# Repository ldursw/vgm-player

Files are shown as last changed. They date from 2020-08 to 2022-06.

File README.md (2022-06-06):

# VGM Player

This project allows VGM (Video Game Music) files from Sega Master System, Sega Game Gear,
and Sega Mega Drive/Genesis to be played on real hardware using the YM2612 sound chip and
the Teensy 3.6 board.

## Features

- Support for Master System, Game Gear, Mega Drive/Genesis
- Standalone player using the SD Card slot
- Can be controlled by a computer using the USB port
- Correct volume for PSG and FM
- Integration with emulators available
- Supports emulated and discrete SN76489
- Uses the Mega Amp circuit for amplification
- Hardware support for Teensy 3.6 and Arduino Due
- Player support for Windows and Linux (experimental)

## Supported boards

| Board | SD Card | Stream | Real PSG | Emulated PSG |
| --- | --- | --- | --- | --- |
| Teensy 3.6 | ✔️ | ✔️ | ✔️ | ✔️ |
| Arduino Due | ❔ | ✔️ | ✔️ | ✔️ |

✔️ Fully supported  
❔ Not tested  

## Demo
- [Instruction streaming from PC](https://www.youtube.com/watch?v=saAEF2lk2_Y)
- [Emulator with hardware sound](https://www.youtube.com/watch?v=Mupbj-XCC5c)
- [44.1kHz playback](https://www.youtube.com/watch?v=DkkqFxyVbDQ)
- [Music recordings](https://www.youtube.com/watch?v=EpjxUjE8uks)

## Difference between other implementations

### PSG

One of the biggest differences between this project and other implementations is that
an emulated PSG is used instead of the discrete SN76489. It is
[widely known](https://www.smspower.org/Development/SN76489#TheLinearFeedbackShiftRegister)
that the Sega version has some differences mainly in the noise channel.

For example, most games get a [weird artifact](https://gitcdn.link/cdn/ldursw/vgm-player/main/assets/panicpuppet-discrete.ogg) instead
of the [expected noise channel](https://gitcdn.link/cdn/ldursw/vgm-player/main/assets/panicpuppet-emulated.ogg).
After Burner II has a constant tone on a [discrete chip](https://gitcdn.link/cdn/ldursw/vgm-player/main/assets/afterburner-discrete.ogg)
whereas [on emulation](https://gitcdn.link/cdn/ldursw/vgm-player/main/assets/afterburner-emulated.ogg) it sounds right.

When using an emulated PSG the microcontroller will emulate the chip and the output is
sent to the `DAC0` pin at 44.1 kHz.

If you want to use a discrete PSG anyway, all you have to do is uncomment `-DUSE_REAL_PSG`
on `hardware/platformio.ini`, connect the `D0..D7` lines from the shift register to the
SN76489 and connect `/WE` to pin 29 though a voltage converter.

### Remote control

Another difference is that the hardware can be controlled via a companion application
written in .NET Core that accepts a generic input class and sends to the hardware via
USB and also displays the current state on screen.

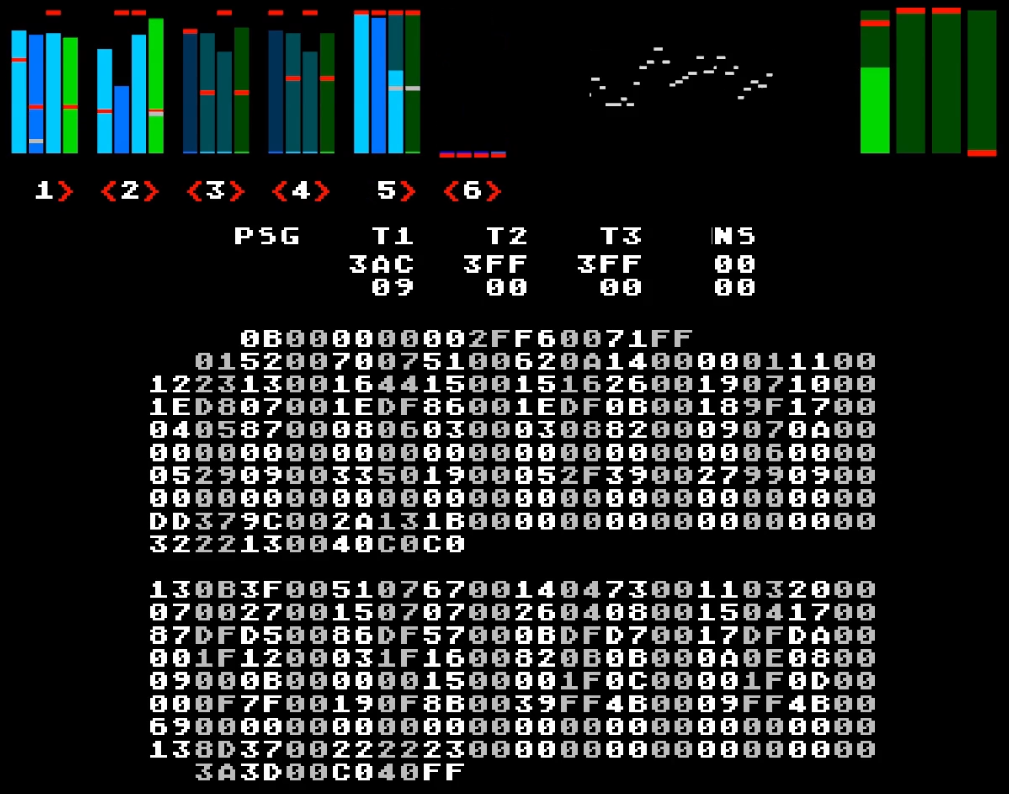
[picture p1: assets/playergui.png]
GUI


There are 3 available input methods. `VgmFile` reads standard `.vgm` and `.vgz` files.
`VgmPipe` creates a named pipe `vgmstream` that accepts commands from other applications,
such as emulators. `VgmPCM` streams 44.1 kHz signed 8-bit mono PCM files to the chip.

## Compiling and Running the project

To compile the code for the hardware you will need [PlatformIO](https://platformio.org/).
You can use the CLI or an IDE with extension support such as Visual Studio Code. After
installing PlatformIO just open the `hardware` directory and upload the code to the board.

To compile the player application you will need the
[.NET Core SDK](https://dotnet.microsoft.com/download). You can use the CLI or an IDE
such as Visual Studio Community or Visual Studio Code. On Linux you may have to install
the `libSDL2` package.

## License

All files in this repository are licensed under GNU General Public License Version 3.

## Credits

Thank you very much for all these awesome people

- Maxim - PSG emulation code
- Dave, Maxim, Valley Bell - VGM Format
- zamaz - [DGen/SDL emulator](https://sourceforge.net/projects/dgen/files/dgen/1.33/)
- Softdev, Eke-Eke - [Genesis Plus GX emulator](https://github.com/ekeeke/Genesis-Plus-GX)
- Ace, Villahed94 - [Mega Amp](https://www.sega-16.com/forum/showthread.php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)
- Stephane-D - [XGM Tool and XGM Player](https://github.com/Stephane-D/SGDK/tree/master/sample/xgm-player)
- SDL Community - [SDL](https://www.libsdl.org/)
- greiman - [SdFat library](https://github.com/greiman/SdFat)
- ivanseidel - [DueTimer library](https://github.com/ivanseidel/DueTimer)

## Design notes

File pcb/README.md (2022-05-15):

## VGM Player PCB

Schematic, KiCad 6 project and gerber files for the VGM player using Teensy 3.6.

This is a 2-layer board made with tolerances compatible with JLCPCB.

## Bill of materials

| Quantity | Item | Notes |
|---|---|---|
| 55 | Femake header socket | 48 for teensy, 7 for SI5351 |
| 10 | Breakaway male headers | 4 for the SX1308 module |
| 4 | 100k SMD 0805 resistor | |
| 3 | 10uF SMD 0805 ceramic capacitor | |
| 3 | 0.1uF SMD 0805 ceramic capacitor | |
| 2 | 47pF THT 2.54' pitch ceramic capacitor | Can be replaced with SMD 0805 |
| 2 | 1uF, 16V electrolytic capacitor | |
| 2 | 10uF, 25V electrolytic capacitor | |
| 2 | 2.2k SMD 0805 resistor | |
| 2 | 4.7k SMD 0805 resistor | |
| 2 | Jumper cap | |
| 1 | 2.1mm Barrel Jack | |
| 1 | SX1308 Step-Up Converter | |
| 1 | 7805 Regulator, TO-220 | |
| 1 | 100uH Inductor CD105 | |
| 1 | Teensy 3.6 with pins | |
| 1 | TXS0108E, TSSOP-20 | |
| 1 | 24-pin DIP socket, wide | |
| 1 | 3.5mm headphone jack, female | |
| 1 | AMS1117-3.3 regulator | |
| 1 | 330r SMD 0805 resistor | |
| 1 | 470r SMD 0805 resistor | |
| 1 | 680r SMD 0805 resistor | |
| 1 | TL072 op-amp | |
| 1 | Adafruit SI5351 Clock Generator | |
| 1 | 74HC595 shift register, SOP-16 | |

## Assembly instructions

- Solder all components but leave the YM2612, Teensy, and clock generator disconnected.
- Make sure the jumper JP2 (near the 7805) is removed.
- Set the jumper J3 (near the barrel jack) to `* [* *] *` (EXT to center pin).
- Apply 5V to the barrel jack, center positive.
- Adjust the step-up module until it reaches 8V at the output.
- Remove power.
- Add a jumper to JP2 and move J3 to `[* *] * *` (VIN to center pin).
- Plug the Teensy, YM2612, and the clock generator into the board.
- Plug the headphone jack to line-in or a powered speaker.
- Connect the Teensy to the PC with an USB cable.
- Use the player in this repo to play music from file or emulator.

## 3D Render





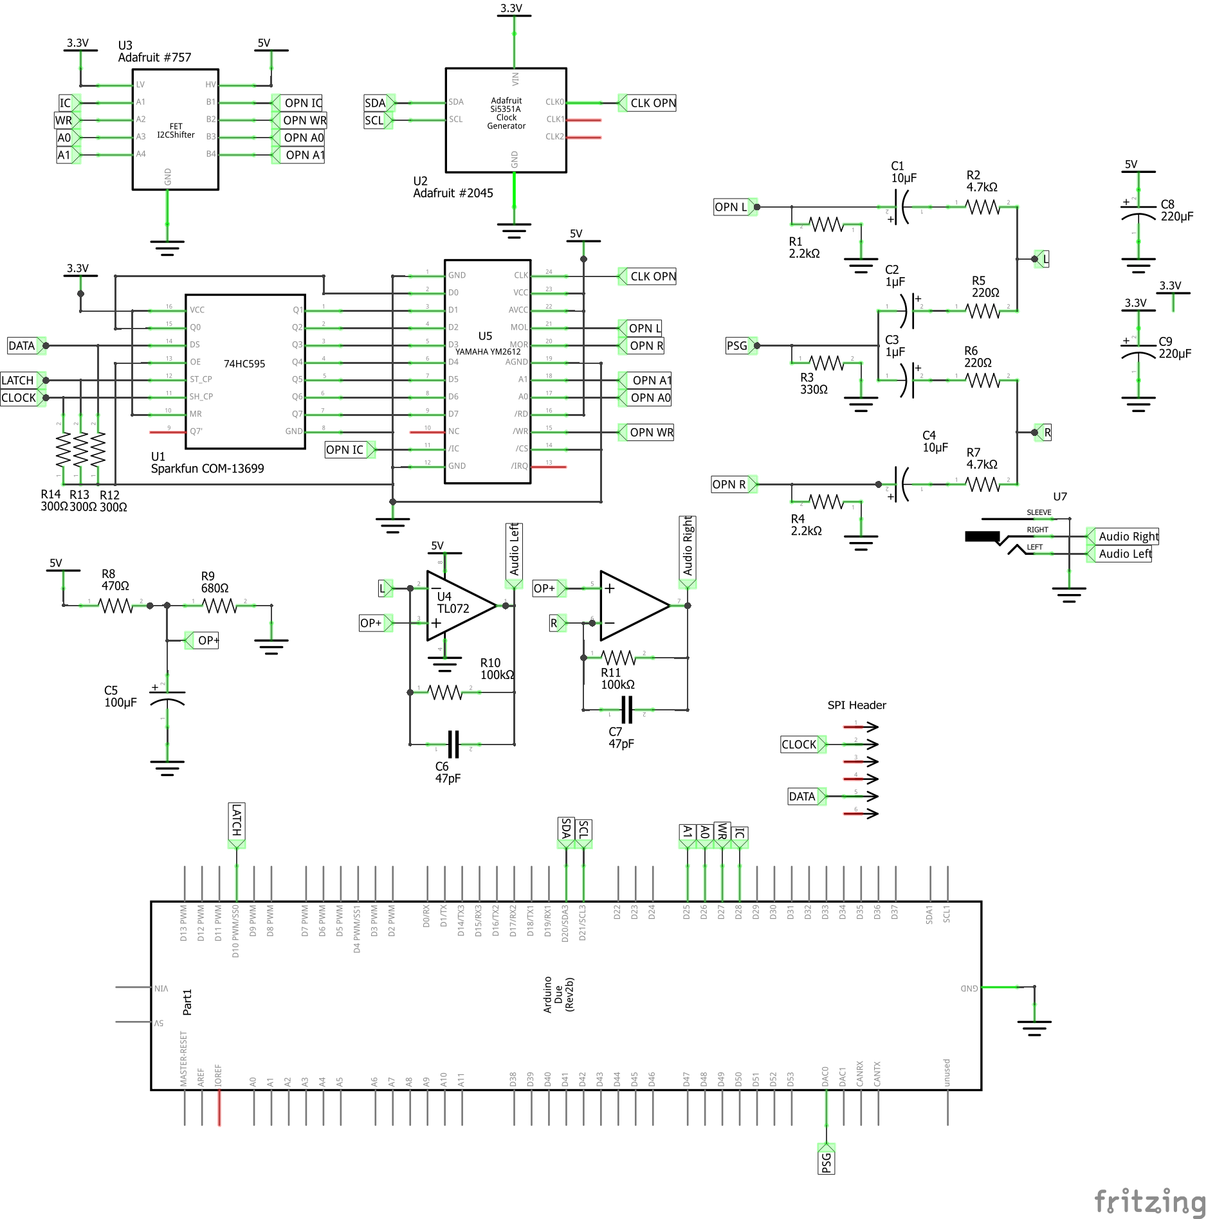
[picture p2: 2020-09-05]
schematics/hardware-due_schem.png

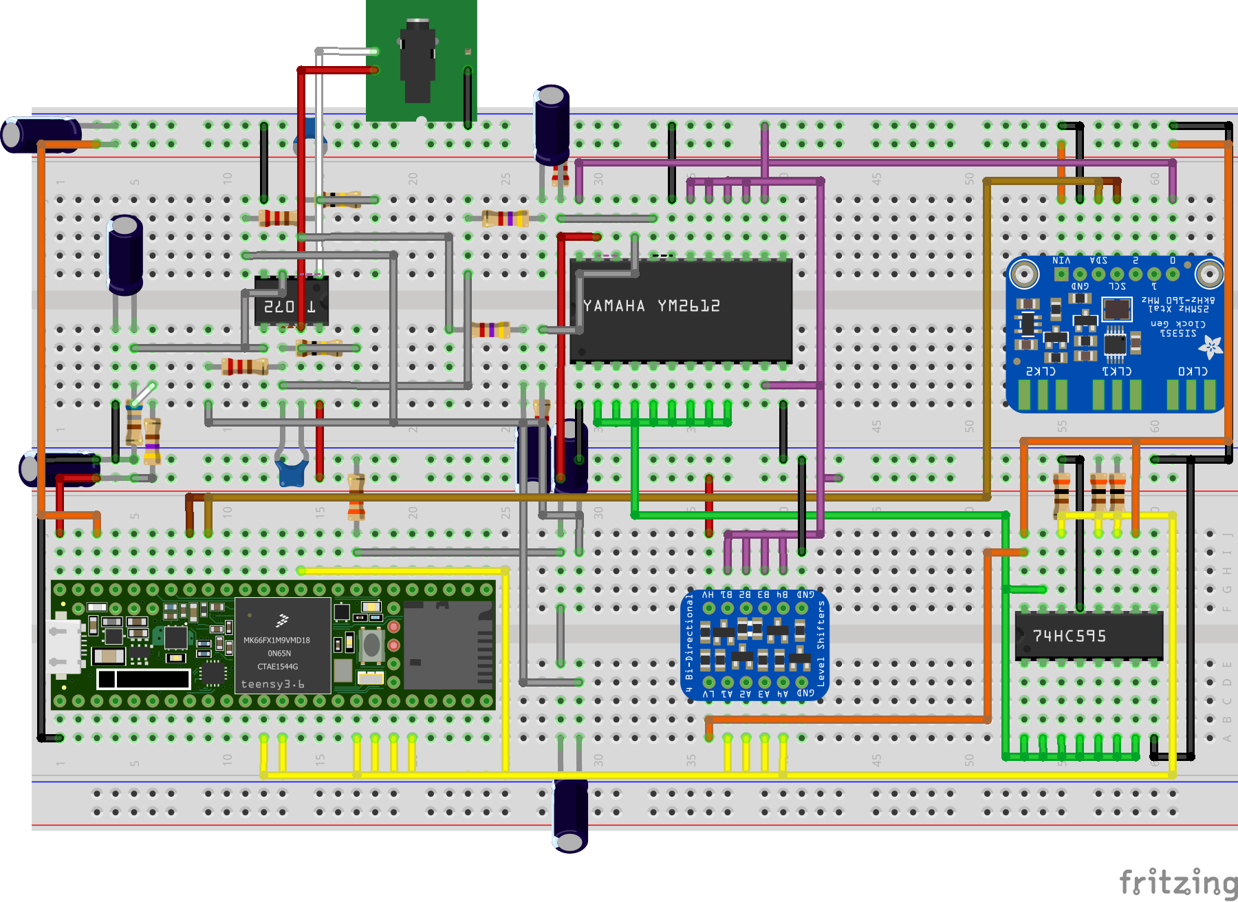
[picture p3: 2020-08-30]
schematics/hardware-teensy36_bb.png

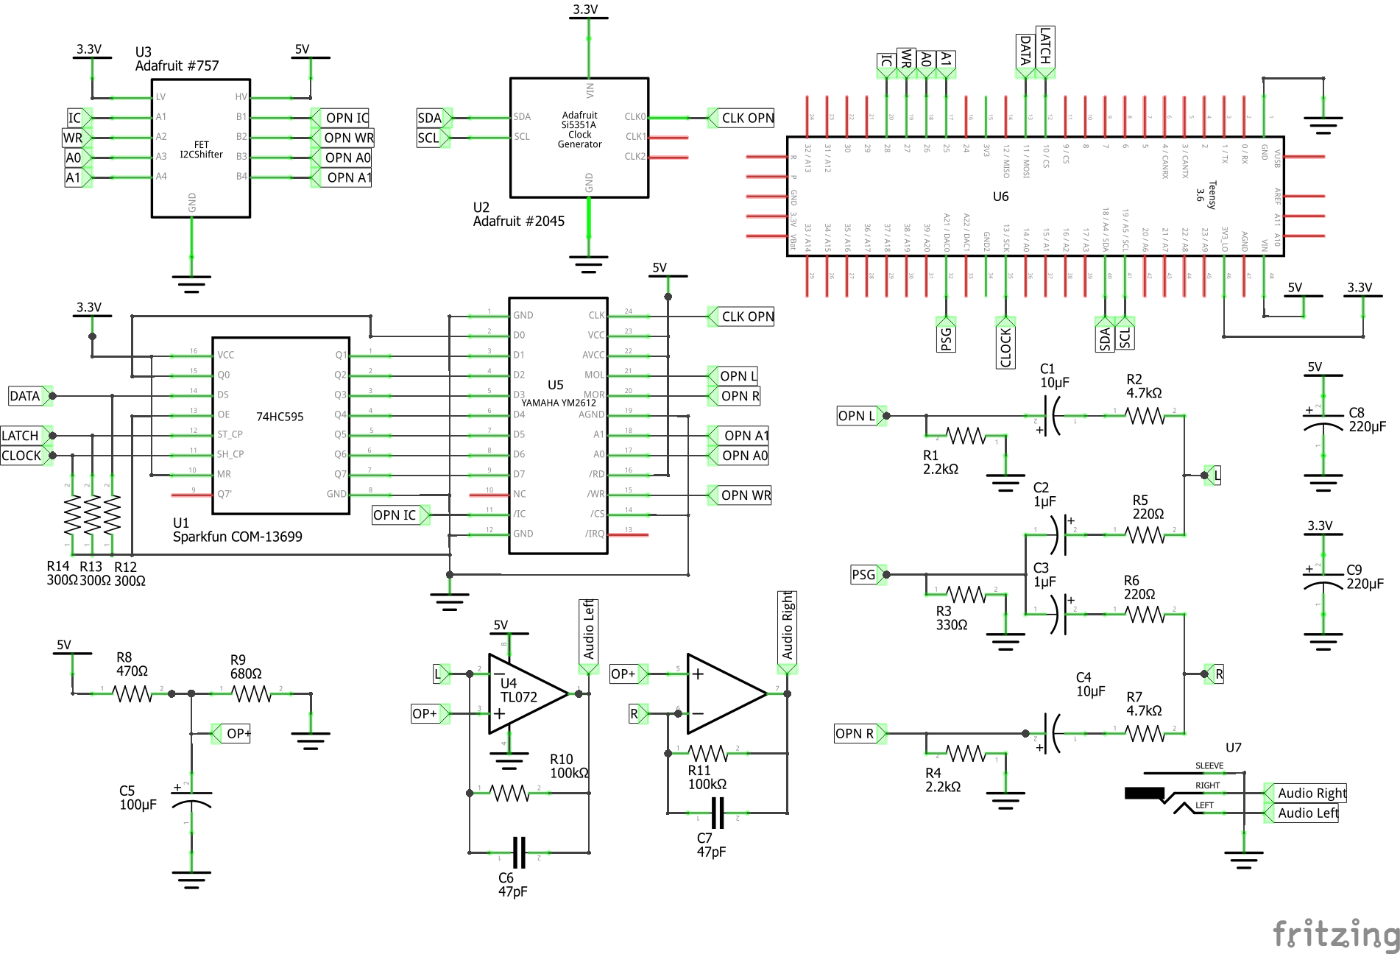
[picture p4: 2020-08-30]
schematics/hardware-teensy36_schem.png

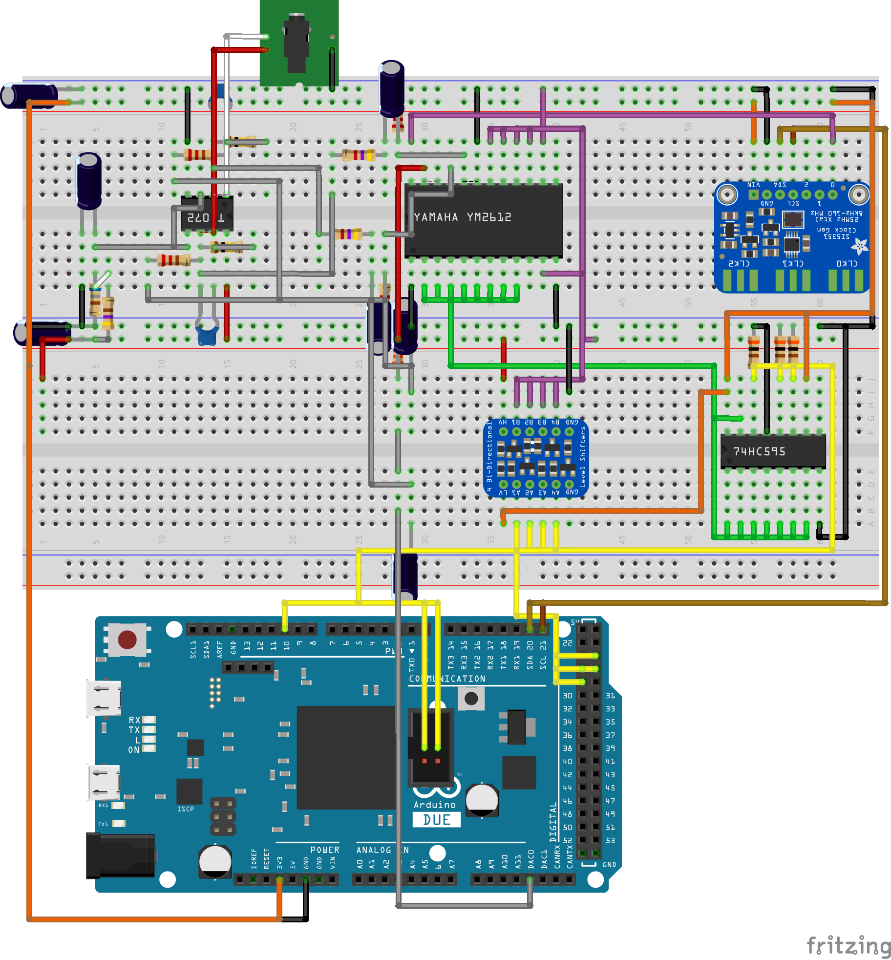
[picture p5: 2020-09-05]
schematics/hardware-due_bb.png

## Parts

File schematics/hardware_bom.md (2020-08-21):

### Assembly List

| Label | Part Type | Properties |
| --- | --- | --- |
C1 | Electrolytic Capacitor | voltage 6.3V; capacitance 10µF; package 100 mil [THT, electrolytic]
C2 | Electrolytic Capacitor | voltage 6.3V; capacitance 1µF; package 100 mil [THT, electrolytic]
C3 | Electrolytic Capacitor | voltage 6.3V; capacitance 1µF; package 100 mil [THT, electrolytic]
C4 | Electrolytic Capacitor | voltage 6.3V; capacitance 10µF; package 100 mil [THT, electrolytic]
C5 | Electrolytic Capacitor | voltage 6.3V; capacitance 100µF; package 100 mil [THT, electrolytic]
C6 | Ceramic Capacitor | voltage 6.3V; capacitance 47pF; package 100 mil [THT, multilayer]
C7 | Ceramic Capacitor | voltage 6.3V; capacitance 47pF; package 100 mil [THT, multilayer]
C8 | Electrolytic Capacitor | voltage 6.3V; capacitance 220µF; package 100 mil [THT, electrolytic]
C9 | Electrolytic Capacitor | voltage 6.3V; capacitance 220µF; package 100 mil [THT, electrolytic]
R1 | 2.2kO Resistor | tolerance ±5%; package THT; pin spacing 400 mil; resistance 2.2kO; bands 4
R2 | 4.7kO Resistor | tolerance ±5%; package THT; pin spacing 400 mil; resistance 4.7kO; bands 4
R3 | 330O Resistor | tolerance ±5%; package THT; pin spacing 400 mil; resistance 330O; bands 4
R4 | 2.2kO Resistor | tolerance ±5%; package THT; pin spacing 400 mil; resistance 2.2kO; bands 4
R5 | 220O Resistor | tolerance ±5%; package THT; pin spacing 400 mil; resistance 220O; bands 4
R6 | 220O Resistor | tolerance ±5%; package THT; pin spacing 400 mil; resistance 220O; bands 4
R7 | 4.7kO Resistor | tolerance ±5%; package THT; pin spacing 400 mil; resistance 4.7kO; bands 4
R8 | 470O Resistor | tolerance ±5%; package THT; pin spacing 400 mil; resistance 470O; bands 4
R9 | 680O Resistor | tolerance ±5%; package THT; pin spacing 400 mil; resistance 680O; bands 4
R10 | 100kO Resistor | tolerance ±5%; package THT; pin spacing 400 mil; resistance 100kO; bands 4
R11 | 100kO Resistor | tolerance ±5%; package THT; pin spacing 400 mil; resistance 100kO; bands 4
R12 | 300O Resistor | tolerance ±5%; package THT; pin spacing 400 mil; resistance 300O; bands 4
R13 | 300O Resistor | tolerance ±5%; package THT; pin spacing 400 mil; resistance 300O; bands 4
R14 | 300O Resistor | tolerance ±5%; package THT; pin spacing 400 mil; resistance 300O; bands 4
U1 | 74HC595 | type 74HC595; package DIP16 [THT]; part # Sparkfun COM-13699
U2 | Adafruit Si5351A Clock Generator | variant variant 1; part # Adafruit #2045
U3 | Adafruit 4-channel I2C-safe Bi-directional Logic Level Converter | variant variant 1; part # Adafruit #757
U4 | TL072 | channels dual; variant variant 1; package dip08; part # TL072
U5 | YAMAHA YM2612 | pins 24; chip label YAMAHA YM2612; true; package DIP (Dual Inline) [THT]; pin spacing 600mil; hole size 1.0mm,0.508mm
U6 | Teensy 3.6 (Basic) | variant variant 1; clock freq. 180 MHz; arch 32 bit; revision 0.51; processor ARM Cortex-M4
U7 | 2.5mm Audio Jack | variant special_pogo_pins; size 2.5mm; package stereojack2.5mm_specia_pogopins

### Shopping List

| Amount | Part Type |
| --- | --- |
3 | 300O Resistor
2 | 220O Resistor
2 | 2.2kO Resistor
2 | 4.7kO Resistor
2 | 100kO Resistor
2 | Electrolytic Capacitor 1µF 6.3V
2 | Electrolytic Capacitor 10µF 6.3V
2 | Electrolytic Capacitor 220µF 6.3V
2 | Ceramic Capacitor 47pF 6.3V
1 | 330O Resistor
1 | 470O Resistor
1 | 680O Resistor
1 | Electrolytic Capacitor 100µF 6.3V
1 | 74HC595
1 | Adafruit Si5351A Clock Generator #2045
1 | Adafruit 4-channel Logic Level Converter #757
1 | TL072
1 | YAMAHA YM2612
1 | Teensy 3.6
1 | 2.5mm Audio Jack

Exported with Fritzing 0.9.4 - [https://fritzing.org](https://fritzing.org)

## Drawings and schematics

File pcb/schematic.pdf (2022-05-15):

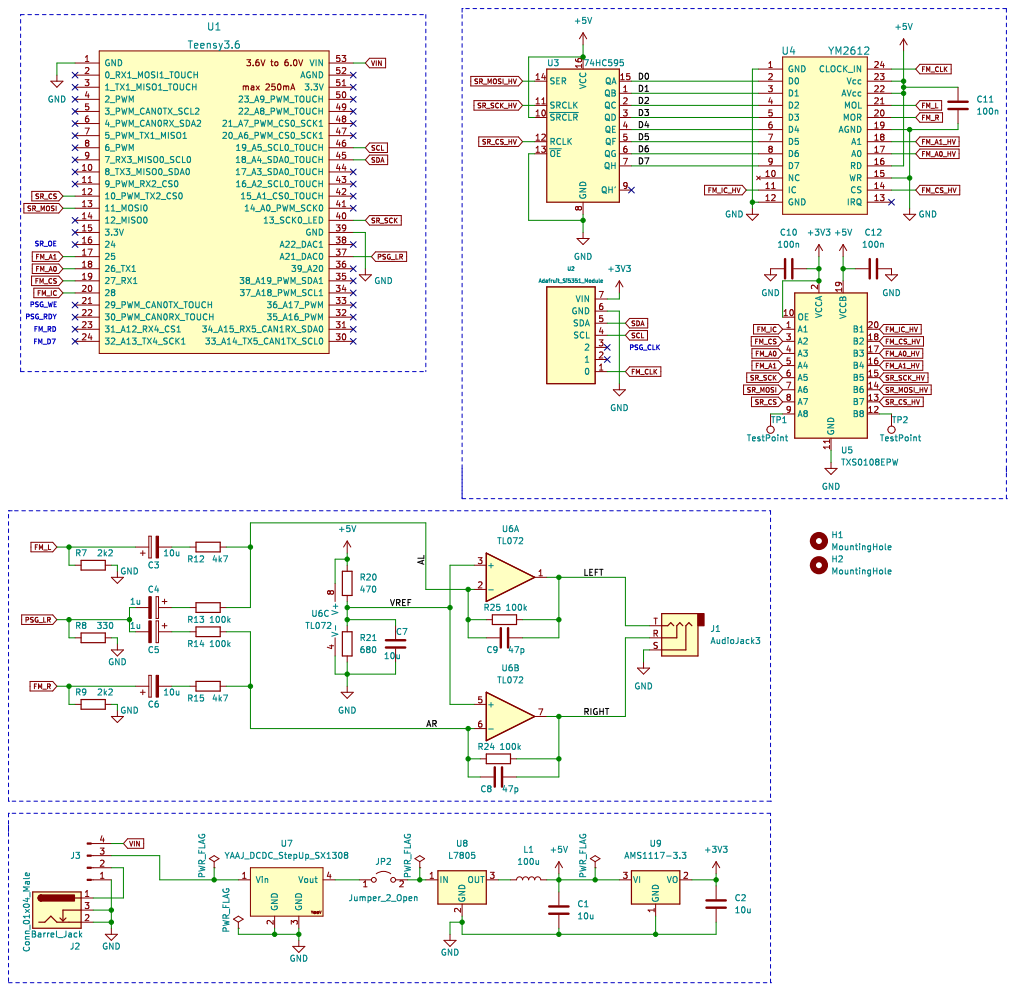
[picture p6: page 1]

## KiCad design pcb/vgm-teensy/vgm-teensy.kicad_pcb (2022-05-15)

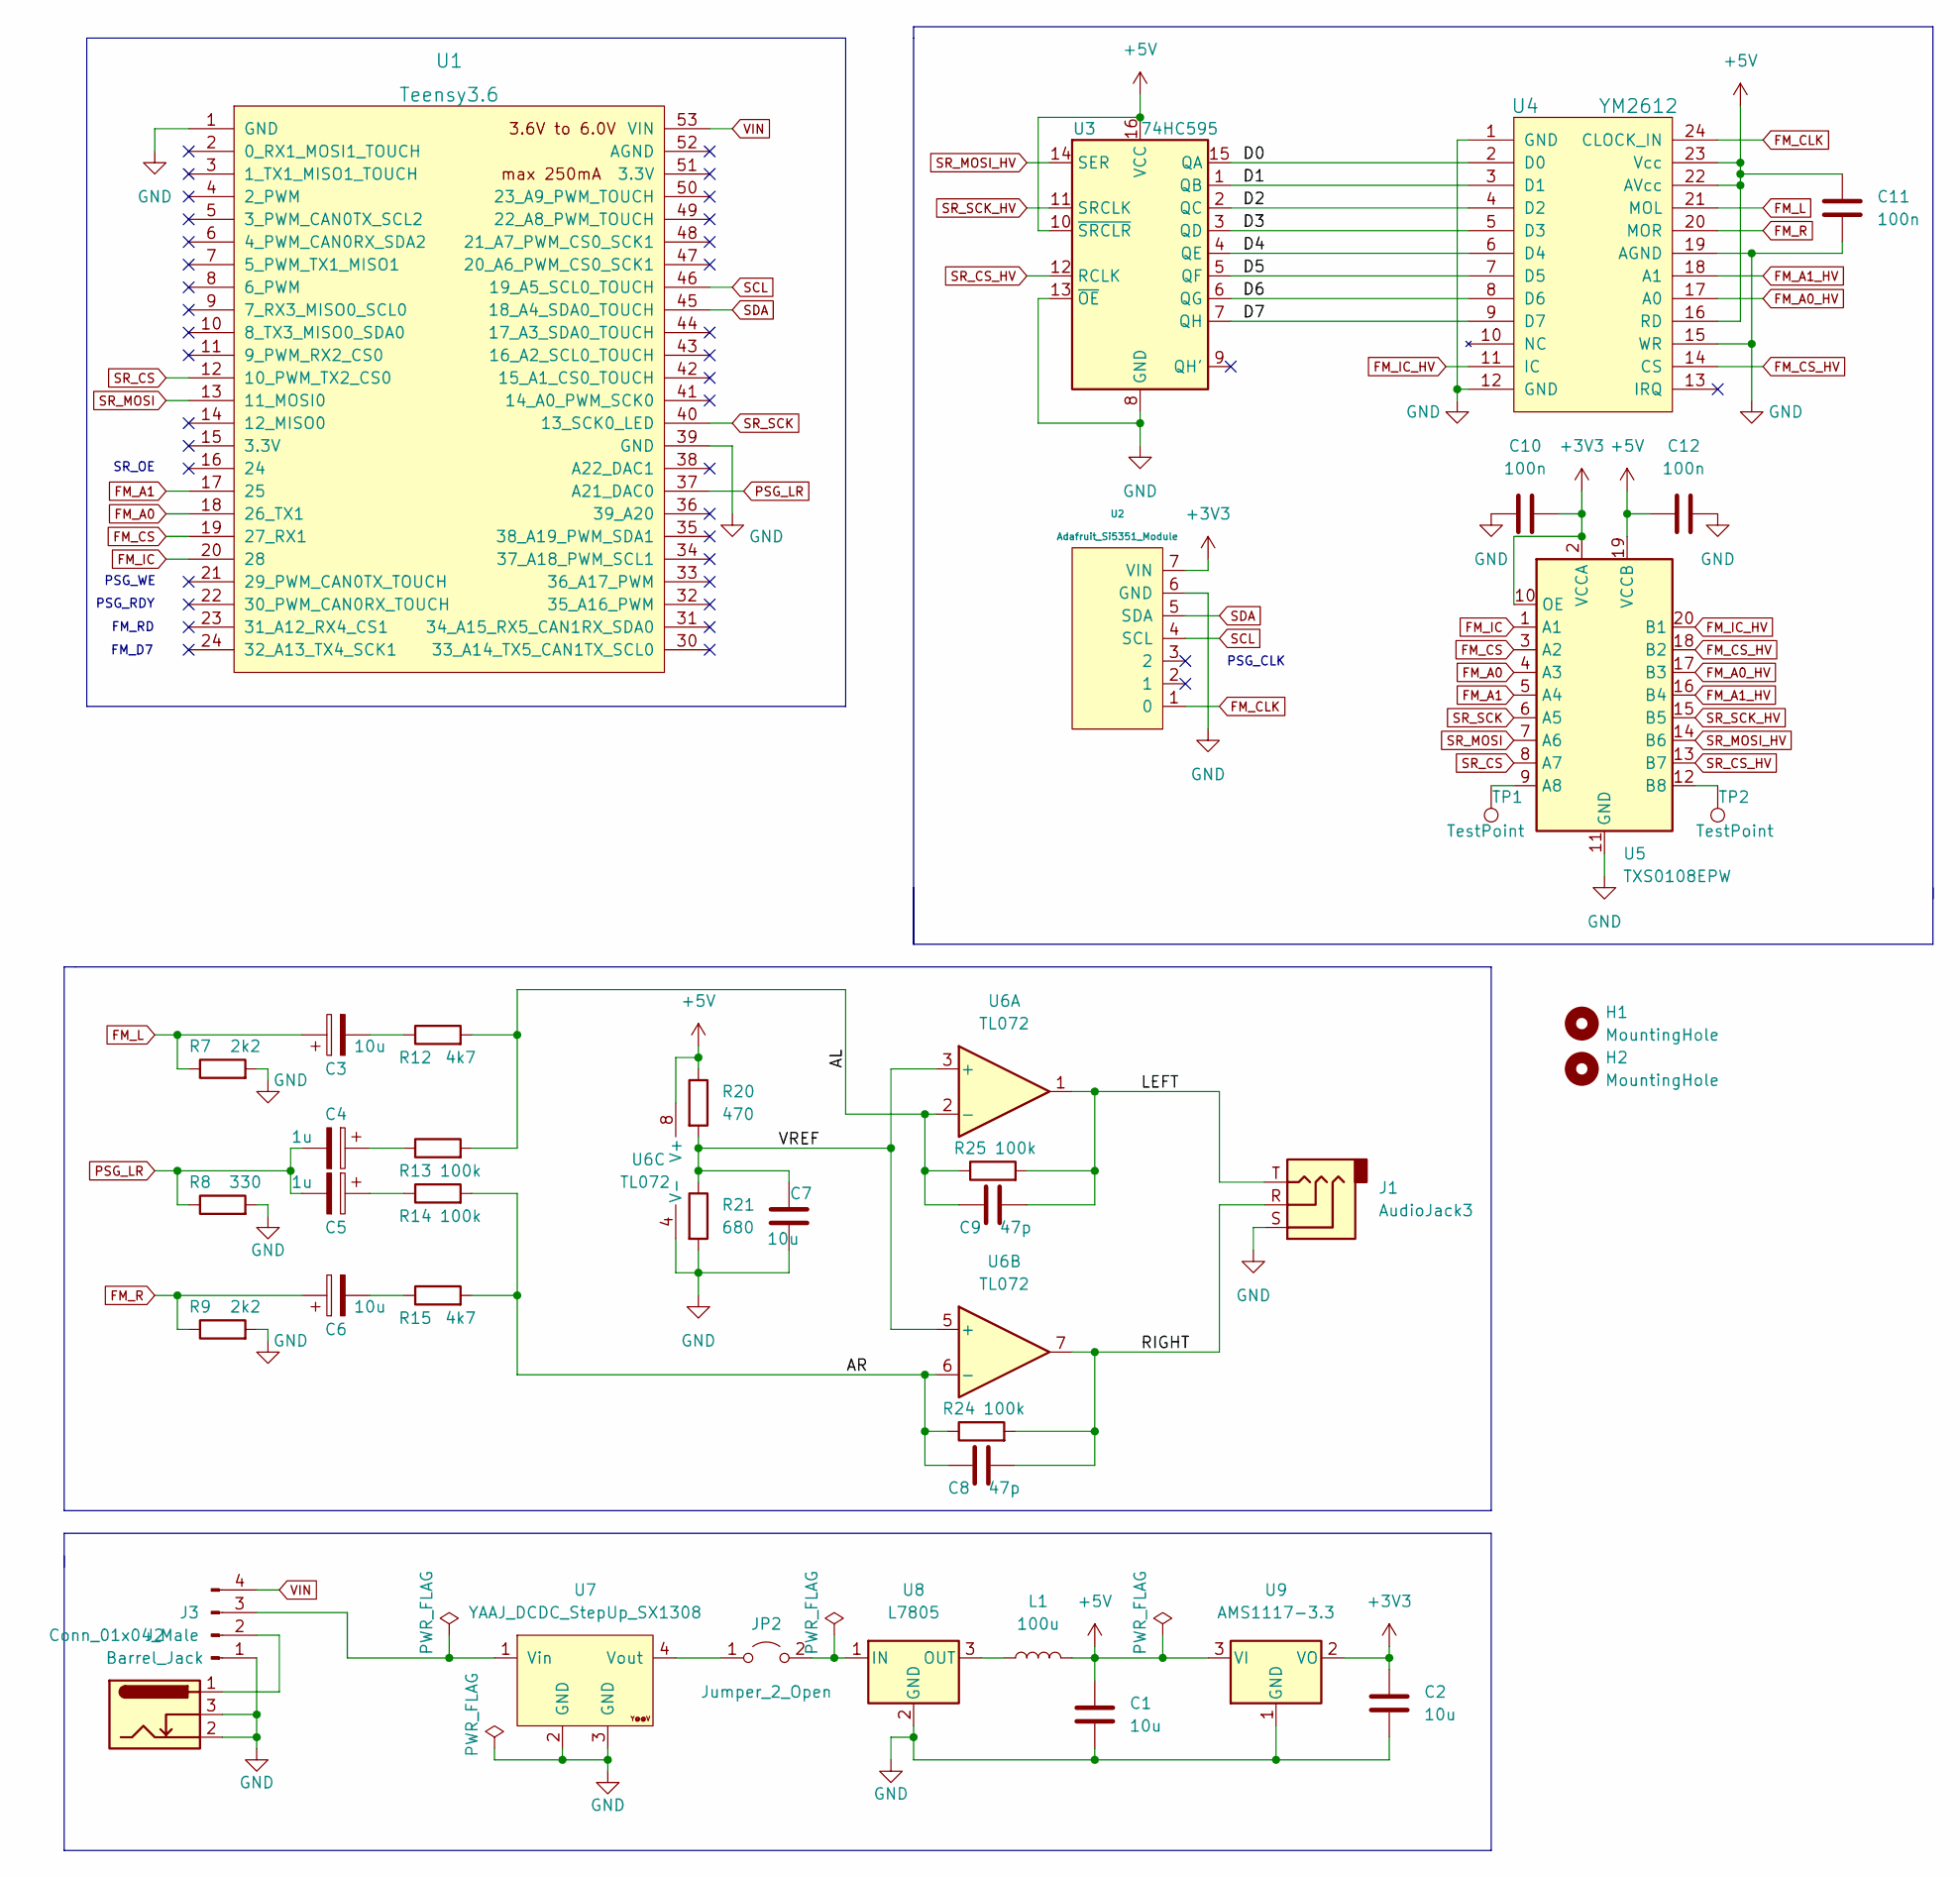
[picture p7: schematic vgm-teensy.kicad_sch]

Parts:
C1, C2, C7: 10u; C_0805_2012Metric_Pad1.18x1.45mm_HandSolder
C3, C6: 10u; CP_Radial_D5.0mm_P2.50mm
C4, C5: 1u; CP_Radial_D5.0mm_P2.50mm
C8, C9: 47p; C_Disc_D3.0mm_W1.6mm_P2.50mm
C10, C11, C12: 100n; C_0805_2012Metric_Pad1.18x1.45mm_HandSolder
H1, H2: MountingHole; MountingHole_3.2mm_M3
J1: AudioJack3; Jack_3.5mm_Lumberg_1503_07_Horizontal
J2: Barrel_Jack; BarrelJack_Horizontal
J3: Conn_01x04_Male; PinHeader_1x04_P2.54mm_Vertical
JP2: Jumper_2_Open; PinHeader_1x02_P2.54mm_Vertical
L1: 100u; Choke_CD105
R7, R9: 2k2; R_0805_2012Metric_Pad1.20x1.40mm_HandSolder
R8: 330; R_0805_2012Metric_Pad1.20x1.40mm_HandSolder
R12, R15: 4k7; R_0805_2012Metric_Pad1.20x1.40mm_HandSolder
R13, R14, R24, R25: 100k; R_0805_2012Metric_Pad1.20x1.40mm_HandSolder
R20: 470; R_0805_2012Metric_Pad1.20x1.40mm_HandSolder
R21: 680; R_0805_2012Metric_Pad1.20x1.40mm_HandSolder
TP1, TP2: TestPoint; TestPoint_Pad_D1.0mm
U1: Teensy3.6; Teensy35_36
U2: Adafruit_Si5351_Module
U3: 74HC595; SOP-16_3.9x9.9mm_P1.27mm
U4: YM2612; DIP-24_W15.24mm_Socket
U5: TXS0108EPW; TSSOP-20_4.4x6.5mm_P0.65mm
U6: TL072; SOIC-8_3.9x4.9mm_P1.27mm
U7: YAAJ_DCDC_StepUp_SX1308
U8: L7805; TO-220-3_Vertical
U9: AMS1117-3.3; SOT-223-3_TabPin2

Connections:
+3V3: C2.1, C10.2, U2.7 (VIN), U5.2 (VCCA), U5.10 (OE), U9.2 (VO)
+5V: C1.1, C11.1, C12.1, L1.2, R20.1, U3.10 (~SRCLR), U3.16 (VCC), U4.16 (RD), U4.22 (AVcc), U4.23 (Vcc), U5.19 (VCCB), U6.8 (V+), U9.3 (VI)
/AL: C9.1, R12.2, R13.2, R25.1, U6.2 (-)
/AR: C8.1, R14.2, R15.2, R24.1, U6.6 (-)
/D0: U3.15 (QA), U4.2 (D0)
/D1: U3.1 (QB), U4.3 (D1)
/D2: U3.2 (QC), U4.4 (D2)
/D3: U3.3 (QD), U4.5 (D3)
/D4: U3.4 (QE), U4.6 (D4)
/D5: U3.5 (QF), U4.7 (D5)
/D6: U3.6 (QG), U4.8 (D6)
/D7: U3.7 (QH), U4.9 (D7)
/LEFT: C9.2, J1.T, R25.2, U6.1
/RIGHT: C8.2, J1.R, R24.2, U6.7
/VREF: C7.1, R20.2, R21.1, U6.3 (+), U6.5 (+)
FM_A0: U1.18 (26_TX1), U5.4 (A3)
FM_A0_HV: U4.17 (A0), U5.17 (B3)
FM_A1: U1.17 (25), U5.5 (A4)
FM_A1_HV: U4.18 (A1), U5.16 (B4)
FM_CLK: U2.1 (0), U4.24 (CLOCK_IN)
FM_CS: U1.19 (27_RX1), U5.3 (A2)
FM_CS_HV: U4.14 (CS), U5.18 (B2)
FM_IC: U1.20 (28), U5.1 (A1)
FM_IC_HV: U4.11 (IC), U5.20 (B1)
FM_L: C3.1, R7.1, U4.21 (MOL)
FM_R: C6.1, R9.1, U4.20 (MOR)
GND: C1.2, C2.2, C7.2, C10.1, C11.2, C12.2, J1.S, J2.2, J2.3, J3.1, R7.2, R8.2, R9.2, R21.2, U1.1 (GND), U1.39 (GND), U2.6 (GND), U3.8 (GND), U3.13 (~OE), U4.1 (GND), U4.12 (GND), U4.15 (WR), U4.19 (AGND), U5.11 (GND), U6.4 (V-), U7.2 (GND), U7.3 (GND), U8.2 (GND), U9.1 (GND)
unnamed: C3.2, R12.1
unnamed: C4.1, R13.1
unnamed: C5.1, R14.1
unnamed: C6.2, R15.1
unnamed: J2.1, J3.2
unnamed: J3.3, U7.1 (Vin)
unnamed: JP2.1 (A), U7.4 (Vout)
unnamed: JP2.2 (B), U8.1 (IN)
unnamed: L1.1, U8.3 (OUT)
unnamed: TP1.1, U5.9 (A8)
unnamed: TP2.1, U5.12 (B8)
PSG_LR: C4.2, C5.2, R8.1, U1.37 (A21_DAC0)
SCL: U1.46 (19_A5_SCL0_TOUCH), U2.4 (SCL)
SDA: U1.45 (18_A4_SDA0_TOUCH), U2.5 (SDA)
SR_CS: U1.12 (10_PWM_TX2_CS0), U5.8 (A7)
SR_CS_HV: U3.12 (RCLK), U5.13 (B7)
SR_MOSI: U1.13 (11_MOSI0), U5.7 (A6)
SR_MOSI_HV: U3.14 (SER), U5.14 (B6)
SR_SCK: U1.40 (13_SCK0_LED), U5.6 (A5)
SR_SCK_HV: U3.11 (SRCLK), U5.15 (B5)
VIN: J3.4, U1.53 (VIN)

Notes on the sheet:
FM_D7
PSG_WE
PSG_CLK
PSG_RDY
FM_RD
SR_OE

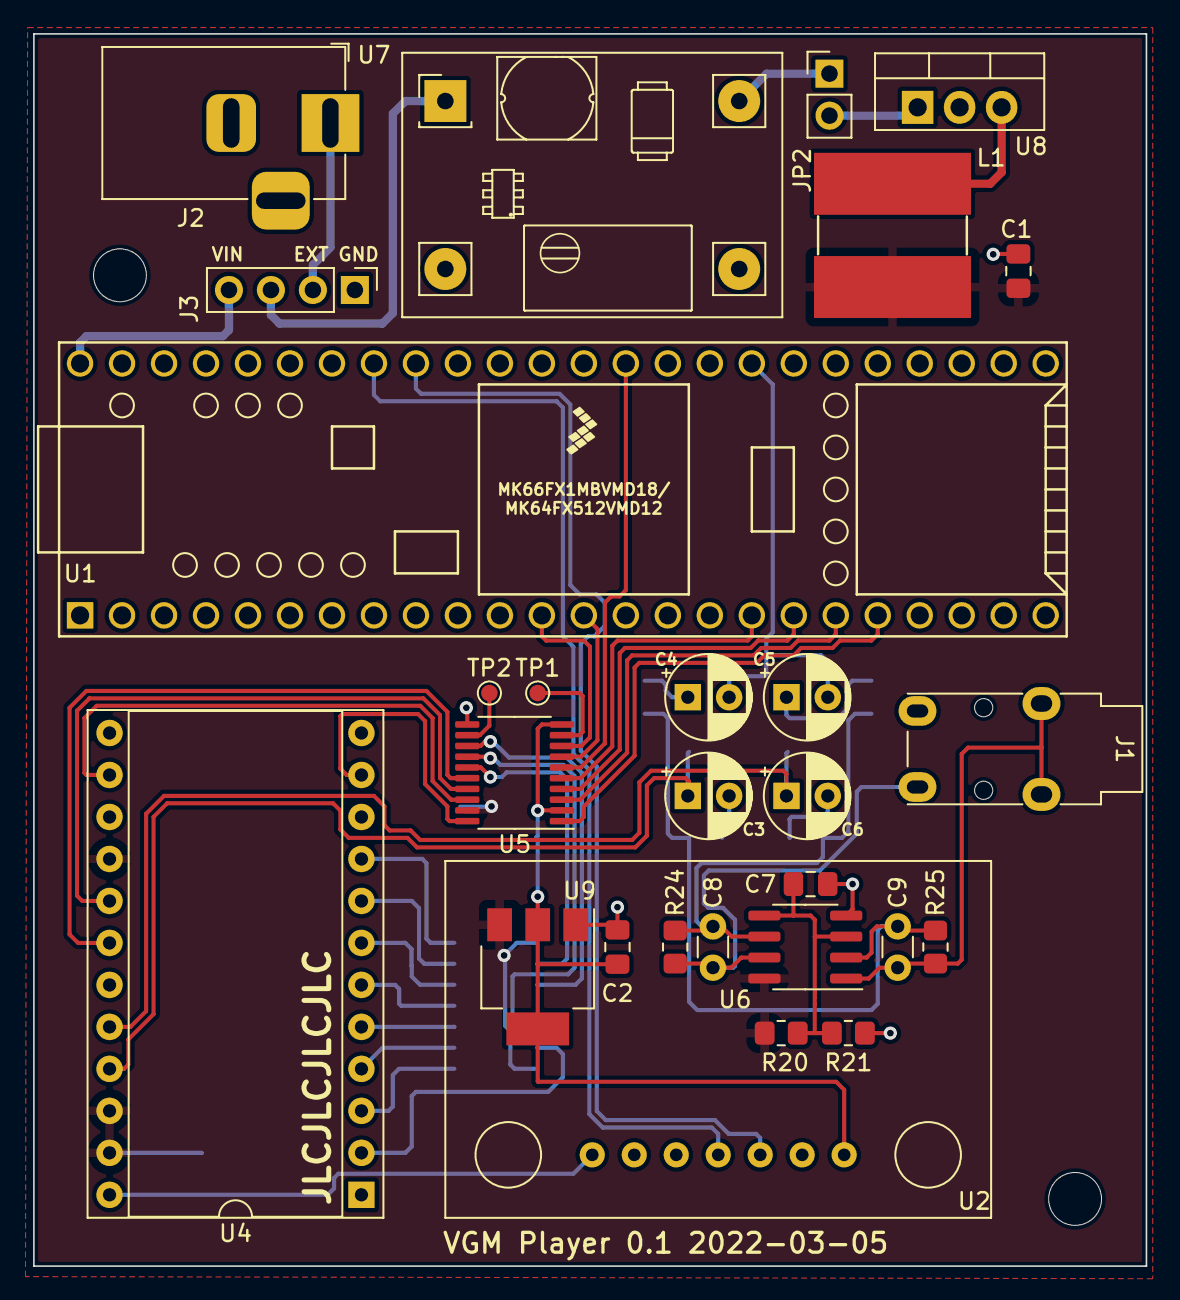
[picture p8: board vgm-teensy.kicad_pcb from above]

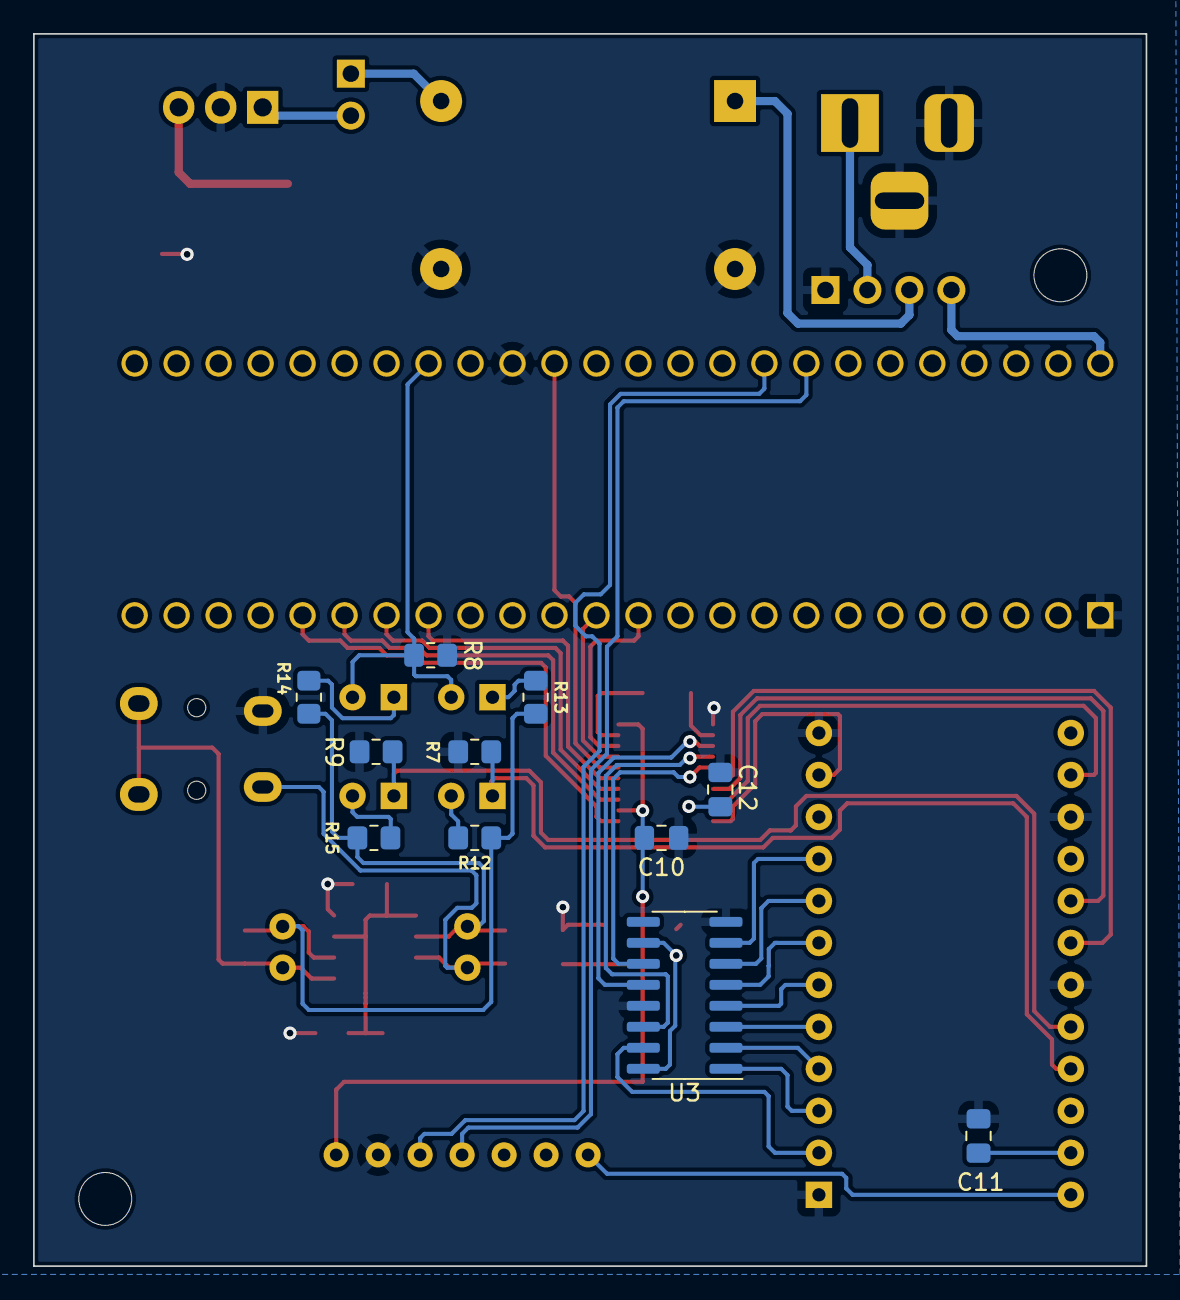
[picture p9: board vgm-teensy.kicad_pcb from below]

Board: 2 copper layers, 67.3 x 74.5 mm, 41 parts (11 on the bottom side), 48 nets.

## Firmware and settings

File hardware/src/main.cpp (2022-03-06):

// SPDX-License-Identifier: GPL-3.0
#include <Arduino.h>
#include "player/dispatcher.hpp"
#include "util/hal.hpp"

#if defined(ENABLE_PLAYER) && defined(ENABLE_STREAM)
#error Player and Stream cannot be activated at the same time
#elif !defined(ENABLE_PLAYER) && !defined(ENABLE_STREAM)
#error Please specify either "ENABLE_PLAYER" or "ENABLE_STREAM"
#endif

#ifdef ENABLE_PLAYER
#include "player/vgmplayer.hpp"
#endif

void setup(void)
{
    // Activity LED
    pinMode(13, OUTPUT);

    Dispatcher::setup();

#ifdef ENABLE_STREAM
    SerialUSB.begin(115200);
#endif

#ifdef ENABLE_PLAYER
    delay(1000);

    if (!VgmPlayer::setup("music.vgm"))
    {
        digitalWriteFast(13, HIGH);

        return;
    }
#endif
}

void loop(void)
{
#ifdef ENABLE_STREAM
    if (Dispatcher::isBufferFull())
    {
        return;
    }

    char buf[4];
    uint8_t index = 0;
    while (index < sizeof(buf))
    {
        index += SerialUSB.readBytes(buf + index, sizeof(buf) - index);
    }

    Dispatcher::enqueue(Instruction(buf[0], buf[1], buf[2]));
#endif
}

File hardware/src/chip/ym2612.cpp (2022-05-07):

// SPDX-License-Identifier: GPL-3.0
#include "ym2612.hpp"
#include "shiftregister.hpp"
#include <Arduino.h>
#include "util/hal.hpp"

void Ym2612::setup(void)
{
    ShiftRegister::setup();

    // setup IC for FM
    pinMode(FM_IC, OUTPUT);
    // setup WR for FM
    pinMode(FM_WR, OUTPUT);
    // setup A0 for FM
    pinMode(FM_A0, OUTPUT);
    // setup A1 for FM
    pinMode(FM_A1, OUTPUT);

    // CS HIGH by default
    digitalWriteFast(FM_WR, HIGH);
    // A0,A1,IC LOW by default
    digitalWriteFast(FM_IC, LOW);
    digitalWriteFast(FM_A0, LOW);
    digitalWriteFast(FM_A1, LOW);

    // reset FM
    delay(10);
    digitalWriteFast(FM_IC, HIGH);
}

void Ym2612::pushData(uint8_t port, uint8_t data)
{
    digitalWriteFast(FM_A0, port & 0x01);
    digitalWriteFast(FM_A1, (port & 0x02) >> 1);

    ShiftRegister::pushData(data);

    // TODO: check ready flag instead of waiting
    digitalWriteFast(FM_WR, LOW);
    delayMicroseconds(2);
    digitalWriteFast(FM_WR, HIGH);
}

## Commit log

2020-08-21 Add Initial Commit
    [hardware.fzz]
2020-08-26 Simplify switch statement
2020-08-26 Replace inline function with loop
    [shiftregister.cpp]
2020-08-30 Change shift register function to SPI class
2020-08-31 Fix serial wait on teensy
    [main.cpp]
2020-09-05 Add PSG attenuation for Arduino Due
2020-09-05 Add conditional for longer wait on Teensy
2020-09-05 Add DAC support for Arduino Due
2020-09-05 Add Arduino Due schematics
    [hardware.fzz]
2020-09-06 Add interrupt guard on reset
2020-09-06 Add interrupt guards
2021-04-23 Add fixed point to PSG emulator
    [fixed.hpp]
2021-07-10 Remove UTF-8 BOM
2021-07-13 Split timer implementations
2022-02-07 Add initial commit for Raspberry Pi Pico
2022-03-06 Add FM filter
2022-05-07 Fix artifact on off-center sample
2022-05-14 Add filters
2022-05-14 Add filter for timer data
2022-05-14 Add key on-off filter
2022-05-14 Add frequency filter
2022-05-15 Add PCB
    [vgm-teensy-B_Cu.gbr, vgm-teensy-B_Mask.gbr, vgm-teensy-B_Silkscreen.gbr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]
